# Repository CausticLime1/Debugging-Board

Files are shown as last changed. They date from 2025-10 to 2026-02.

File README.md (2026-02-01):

# Sharkbyte Debugger Board

## Purpose of Project

The purpose of this project is to develop a budget-friendly electronics debugging station that includes various PCBs (Printed Circuit Boards) that incorporate different functionalities. 
A self-designed main board will be used to handle the data processing to display the outputs of the various peripheral boards. The peripheral boards will each have their own functionality and use such 
as an oscilloscope, multimeter, function generator, logic analyzer, variable DC power supply, and CAN Bus debugger. Each board will have a data connector utilizing various GPIO and communication protocols such as
**UART, SPI, and PSSI** as well as a power connector that is handled by the power management system on the main board. 

## Main Board

The central board that all peripheral boards connects to and handles data processing pipeline to a computer. This board has a power management system uses a central 5V rail to provide to a 3.3V LDO for microcontroller logic, and +-12V for operational amplifiers. 

# Notes for Board Redesign

- Make sure boot capacitor for 5V is before the inductor
- Add GPIO reset pin to USB3300

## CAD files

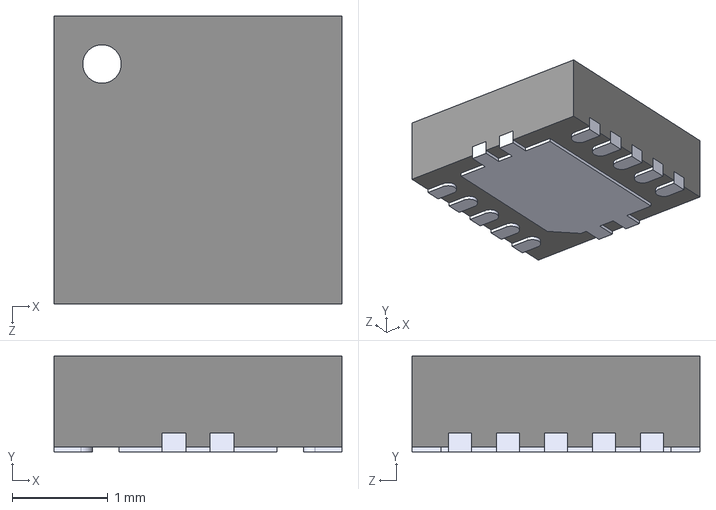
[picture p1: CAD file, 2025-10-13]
Project_Library/ADS8866IDRCR/ADS8866IDRCR.step
3.00 x 1.00 x 3.00 mm

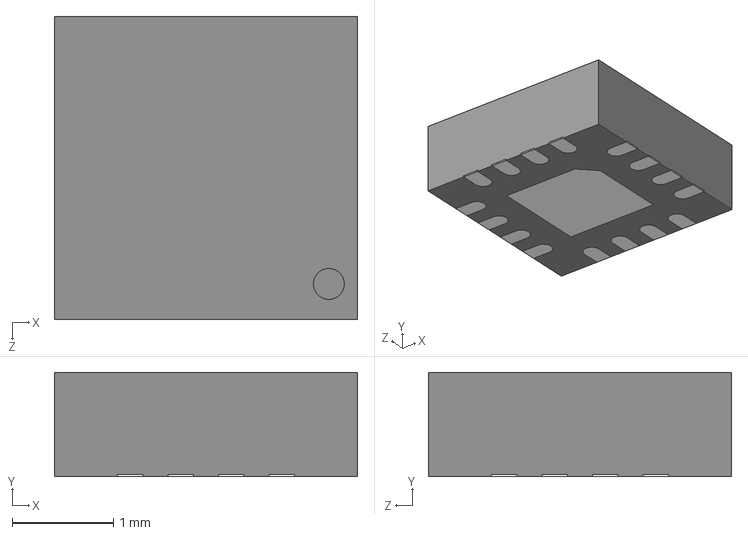
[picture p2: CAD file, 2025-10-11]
Project_Library/LT8609SIV_PBF/LT8609SIV_PBF.step
3.00 x 1.03 x 3.00 mm

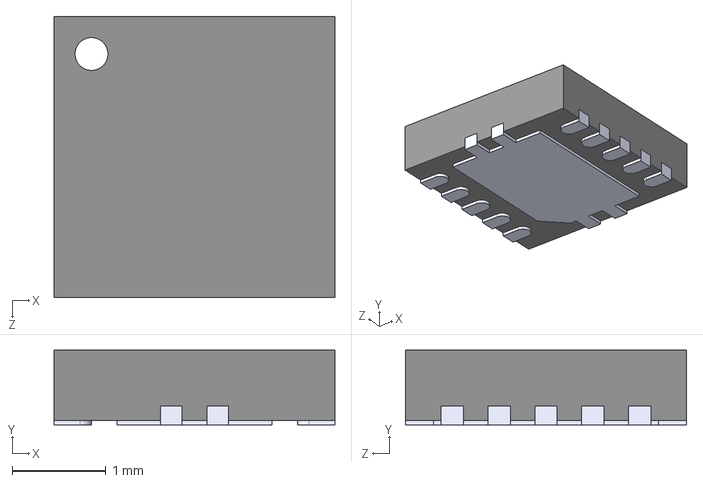
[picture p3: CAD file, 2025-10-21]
Project_Library/PTPS7A9401DSCR/PTPS7A9401DSCR.step
3.00 x 0.8 x 3.00 mm

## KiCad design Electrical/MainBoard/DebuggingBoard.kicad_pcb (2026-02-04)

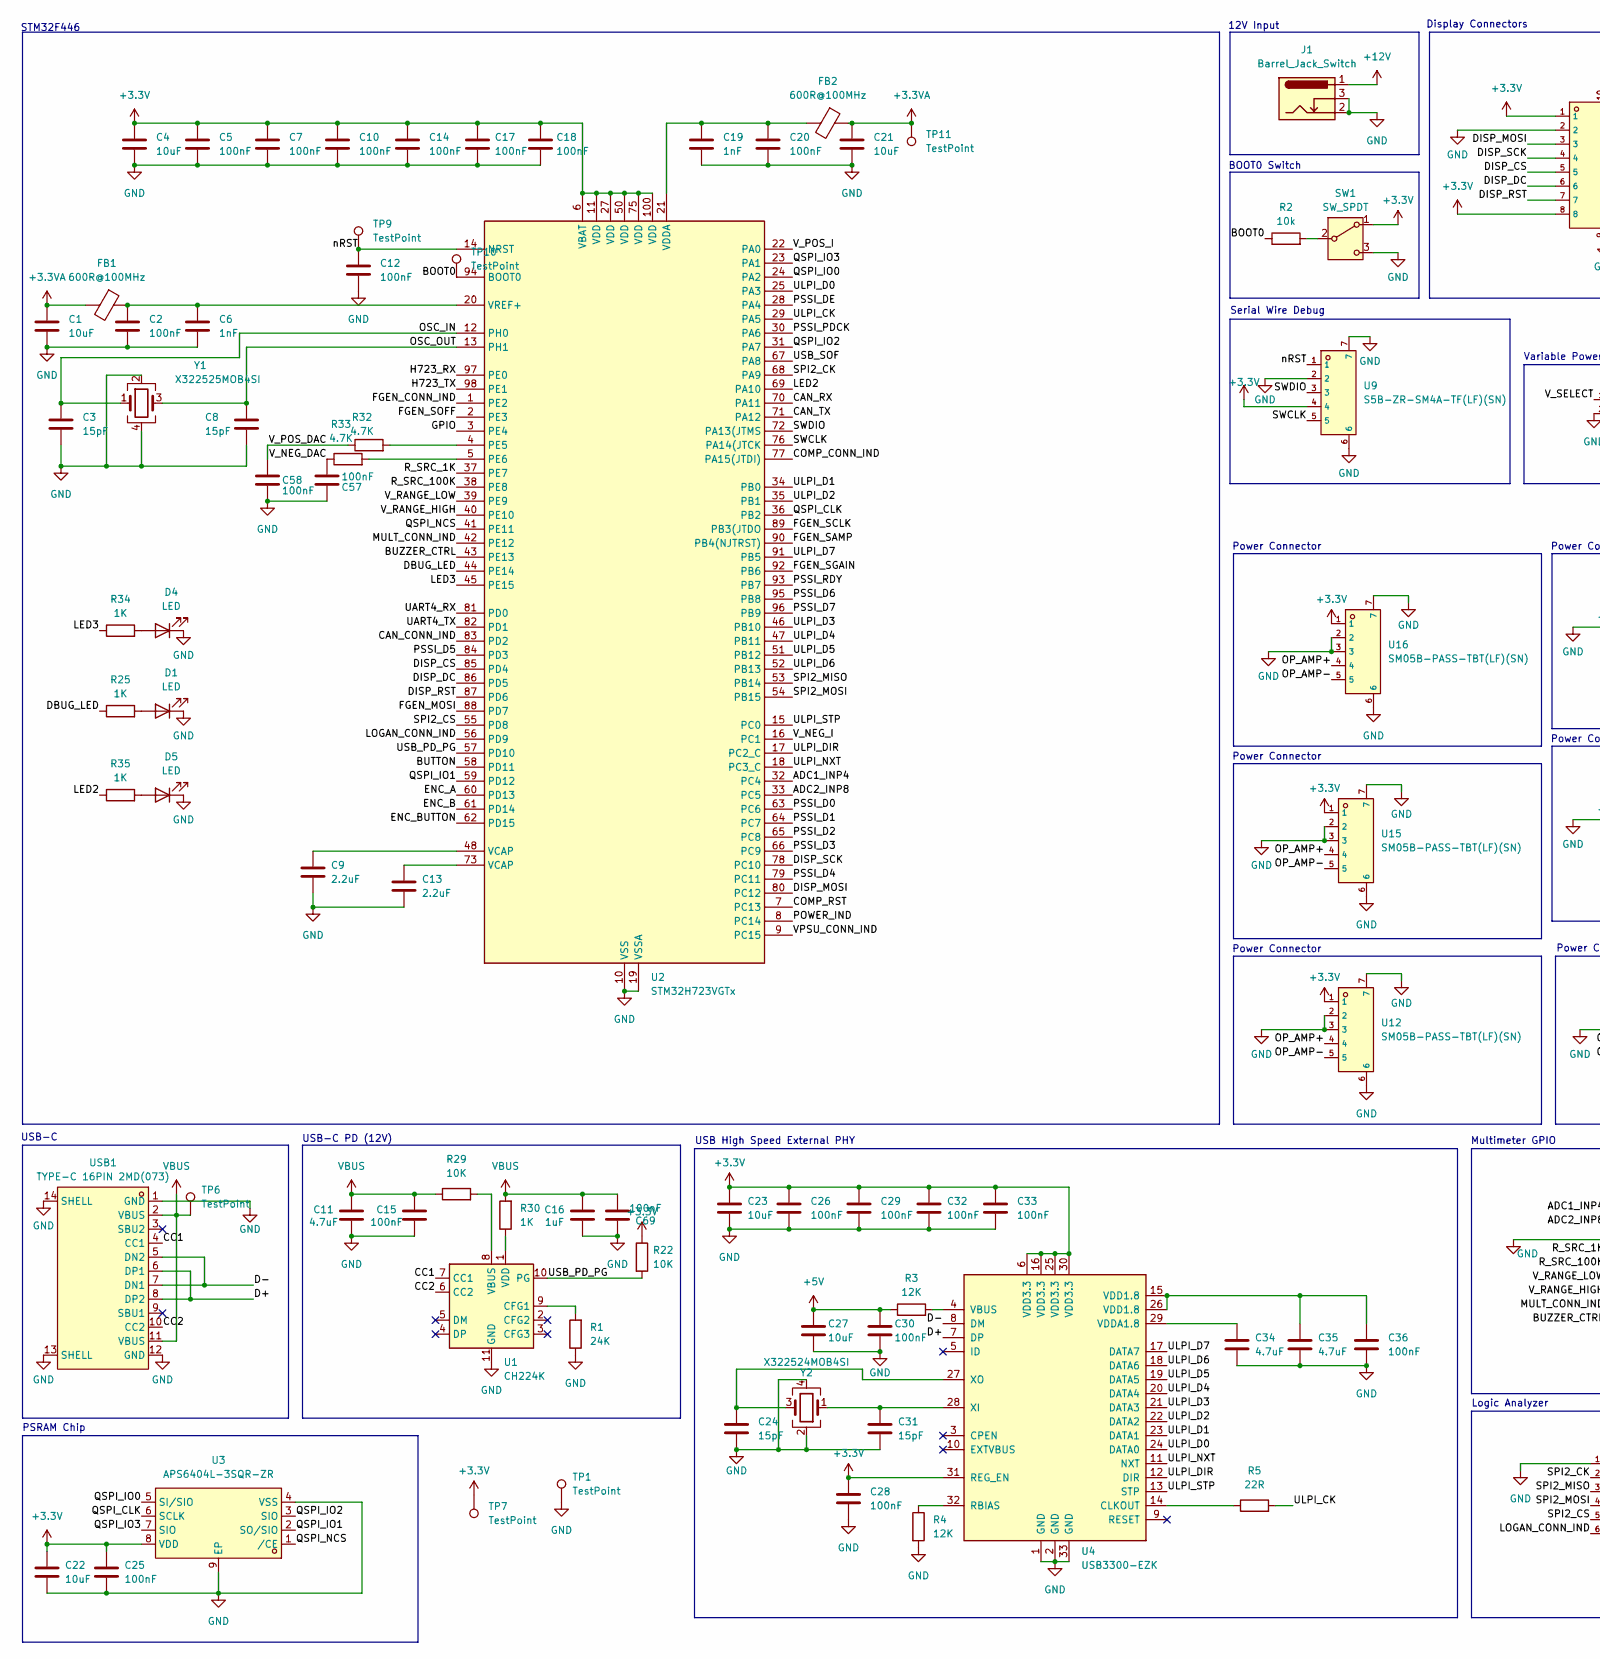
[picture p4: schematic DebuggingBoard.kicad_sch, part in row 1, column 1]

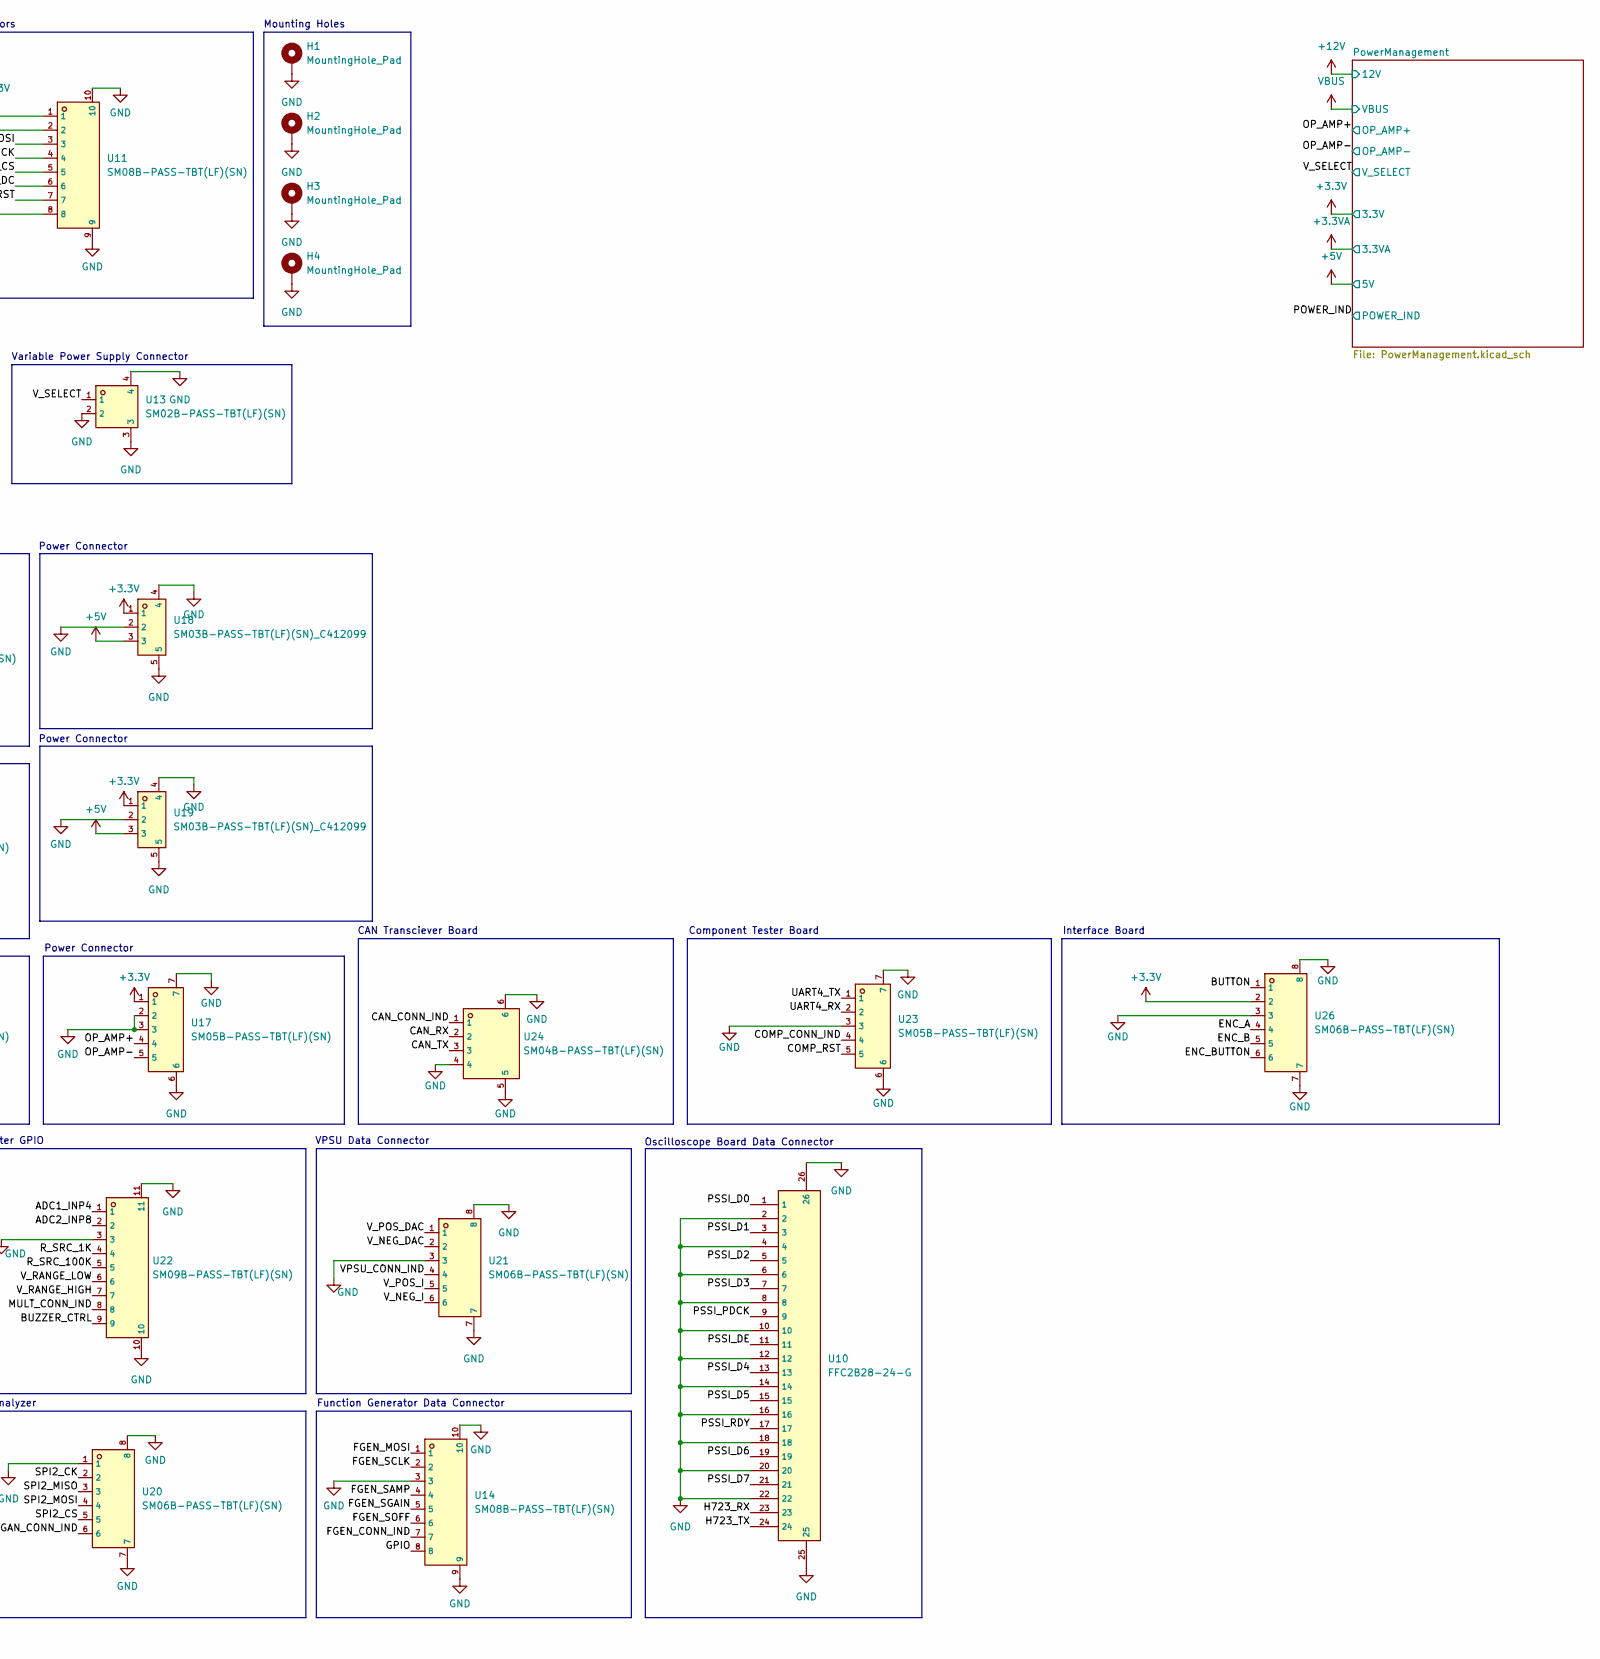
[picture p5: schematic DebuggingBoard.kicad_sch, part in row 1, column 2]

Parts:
C1, C4, C21, C22, C23, C27: 10uF; C_0603_1608Metric
C2, C5, C7, C10, C12, C14, C15, C17, C18, C20, C25, C26, C28, C29, C30, C32, C33, C36, C57, C58, C69: 100nF; C_0402_1005Metric
C3, C8, C24, C31: 15pF; C_0402_1005Metric
C6, C19: 1nF; C_0402_1005Metric
C9, C13: 2.2uF; C_0603_1608Metric
C11: 4.7uF; C_0603_1608Metric
C16: 1uF; C_0603_1608Metric
C34, C35: 4.7uF; C_0402_1005Metric
D1, D4, D5: LED; LED_0603_1608Metric
FB1, FB2: 600R@100MHz; L_0805_2012Metric
H1, H2, H3, H4: MountingHole_Pad; MountingHole_3.2mm_M3_Pad_Via
J1: Barrel_Jack_Switch; BarrelJack_Kycon_KLDX-0202-xC_Horizontal
R1: 24K; R_0603_1608Metric
R2: 10k; R_0402_1005Metric
R3, R4: 12K; R_0402_1005Metric
R5: 22R; R_0402_1005Metric
R22, R29: 10K; R_0402_1005Metric
R25, R34, R35: 1K; R_0402_1005Metric
R30: 1K; R_0603_1608Metric
R32, R33: 4.7K; R_0402_1005Metric
SW1: SW_SPDT; SW_SPDT_CK_JS102011SAQN
TP1, TP6, TP7, TP9, TP10, TP11: TestPoint; TestPoint_Pad_D2.0mm
U1: CH224K; SSOP-10-1EP_3.9x4.9mm_P1mm_EP2.1x3.3mm
U2: STM32H723VGTx; LQFP-100_14x14mm_P0.5mm
U3: APS6404L-3SQR-ZR; USON-8_L3.0-W2.0-P0.50-BL-EP; LCSC Part C3040877
U4: USB3300-EZK; QFN-32-1EP_5x5mm_P0.5mm_EP3.45x3.45mm
U9: S5B-ZR-SM4A-TF(LF)(SN); CONN-SMD_5P-P1.50_S5B-ZR-SM4A-TF-LF-SN; LCSC C485355
U10: FFC2B28-24-G; FPC-SMD_24P-P0.50_XKB_X05A10L24G; LCSC C3151659
U11, U14: SM08B-PASS-TBT(LF)(SN); CONN-SMD_SM08B-PASS-TBT-LF-SN; LCSC C496230
U12, U15, U16, U17, U23: SM05B-PASS-TBT(LF)(SN); CONN-SMD_5P-P2.00_SM05B-PASS-TBT-LF-SN; LCSC C485350
U13: SM02B-PASS-TBT(LF)(SN); CONN-SMD_SM02B-PASS-TBT; LCSC C265417
U18, U19: SM03B-PASS-TBT(LF)(SN)_C412099; CONN-SMD_SM03B-PASS-TBT; LCSC C412099
U20, U21, U26: SM06B-PASS-TBT(LF)(SN); CONN-SMD_SM06B-PASS-TBT; LCSC C489711
U22: SM09B-PASS-TBT(LF)(SN); CONN-SMD_SM09B-PASS-TBT; LCSC C489712
U24: SM04B-PASS-TBT(LF)(SN); CONN-SMD_SM04B-PASS-TBT-LF-SN; LCSC C265073
USB1: TYPE-C 16PIN 2MD(073); USB-C-SMD_TYPE-C-6PIN-2MD-073; LCSC Part C2765186
Y1: X322525MOB4SI; Crystal_SMD_3225-4Pin_3.2x2.5mm
Y2: X322524MOB4SI; Crystal_SMD_3225-4Pin_3.2x2.5mm

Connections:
+3.3V: C4.1, C5.1, C7.1, C10.1, C14.1, C17.1, C18.1, C22.1, C23.1, C25.1, C26.1, C28.1, C29.1, C32.1, C33.1, R22.1, SW1.1 (A), TP7.1, U2.6 (VBAT), U2.11 (VDD), U2.27 (VDD), U2.50 (VDD), U2.75 (VDD), U2.100 (VDD), U3.8 (VDD), U4.6 (VDD3.3), U4.16 (VDD3.3), U4.25 (VDD3.3), U4.30 (VDD3.3), U4.31 (REG_EN), U9.4, U11.1, U11.8, U12.1, U15.1, U16.1, U17.1, U18.1, U19.1, U26.2; also elsewhere on the board
+3.3VA: C1.1, C21.1, FB1.2, FB2.1, TP11.1; also elsewhere on the board
+5V: C27.1, C30.1, R3.1, U18.3, U19.3; also elsewhere on the board
+12V: J1.1; also elsewhere on the board
/ADC1_INP4: U2.32 (PC4), U22.1
/ADC2_INP8: U2.33 (PC5), U22.2
/BOOT0: R2.1, TP10.1, U2.94 (BOOT0)
/BUTTON: U2.58 (PD11), U26.1
/BUZZER_CTRL: U2.43 (PE13), U22.9
/CAN_CONN_IND: U2.83 (PD2), U24.1
/CAN_RX: U2.70 (PA11), U24.2
/CAN_TX: U2.71 (PA12), U24.3
/CC1: U1.7 (CC1), USB1.4 (CC1)
/CC2: U1.6 (CC2), USB1.10 (CC2)
/COMP_CONN_IND: U2.77 (PA15(JTDI)), U23.4
/COMP_RST: U2.7 (PC13), U23.5
/D+: U4.7 (DP), USB1.6 (DP1), USB1.8 (DP2)
/D-: U4.8 (DM), USB1.5 (DN2), USB1.7 (DN1)
/DBUG_LED: R25.1, U2.44 (PE14)
/DISP_CS: U2.85 (PD4), U11.5
/DISP_DC: U2.86 (PD5), U11.6
/DISP_MOSI: U2.80 (PC12), U11.3
/DISP_RST: U2.87 (PD6), U11.7
/DISP_SCK: U2.78 (PC10), U11.4
/ENC_A: U2.60 (PD13), U26.4
/ENC_B: U2.61 (PD14), U26.5
/ENC_BUTTON: U2.62 (PD15), U26.6
/FGEN_CONN_IND: U2.1 (PE2), U14.7
/FGEN_MOSI: U2.88 (PD7), U14.1
/FGEN_SAMP: U2.90 (PB4(NJTRST)), U14.4
/FGEN_SCLK: U2.89 (PB3(JTDO), U14.2
/FGEN_SGAIN: U2.92 (PB6), U14.5
/FGEN_SOFF: U2.2 (PE3), U14.6
/GPIO: U2.3 (PE4), U14.8
/H723_RX: U2.97 (PE0), U10.23
/H723_TX: U2.98 (PE1), U10.24
/LED2: R35.1, U2.69 (PA10)
/LED3: R34.1, U2.45 (PE15)
/LOGAN_CONN_IND: U2.56 (PD9), U20.6
/MULT_CONN_IND: U2.42 (PE12), U22.8
/OP_AMP+: U12.4, U15.4, U16.4, U17.4; also elsewhere on the board
/OP_AMP-: U12.5, U15.5, U16.5, U17.5; also elsewhere on the board
/OSC_IN: C3.1, U2.12 (PH0), Y1.1
/OSC_OUT: C8.1, U2.13 (PH1), Y1.3
/POWER_IND: U2.8 (PC14); also elsewhere on the board
/PSSI_D0: U2.63 (PC6), U10.1
/PSSI_D1: U2.64 (PC7), U10.3
/PSSI_D2: U2.65 (PC8), U10.5
/PSSI_D3: U2.66 (PC9), U10.7
/PSSI_D4: U2.79 (PC11), U10.13
/PSSI_D5: U2.84 (PD3), U10.15
/PSSI_D6: U2.95 (PB8), U10.19
/PSSI_D7: U2.96 (PB9), U10.21
/PSSI_DE: U2.28 (PA4), U10.11
/PSSI_PDCK: U2.30 (PA6), U10.9
/PSSI_RDY: U2.93 (PB7), U10.17
/QSPI_CLK: U2.36 (PB2), U3.6 (SCLK)
/QSPI_IO0: U2.24 (PA2), U3.5 (SI/SIO)
/QSPI_IO1: U2.59 (PD12), U3.2 (SO/SIO)
/QSPI_IO2: U2.31 (PA7), U3.3 (SIO)
/QSPI_IO3: U2.23 (PA1), U3.7 (SIO)
/QSPI_NCS: U2.41 (PE11), U3.1 (/CE)
/R_SRC_1K: U2.37 (PE7), U22.4
/R_SRC_100K: U2.38 (PE8), U22.5
/SPI2_CK: U2.68 (PA9), U20.2
/SPI2_CS: U2.55 (PD8), U20.5
/SPI2_MISO: U2.53 (PB14), U20.3
/SPI2_MOSI: U2.54 (PB15), U20.4
/SWCLK: U2.76 (PA14(JTCK), U9.5
/SWDIO: U2.72 (PA13(JTMS), U9.3
/UART4_RX: U2.81 (PD0), U23.2
/UART4_TX: U2.82 (PD1), U23.1
/ULPI_CK: R5.2, U2.29 (PA5)
/ULPI_D0: U2.25 (PA3), U4.24 (DATA0)
/ULPI_D1: U2.34 (PB0), U4.23 (DATA1)
/ULPI_D2: U2.35 (PB1), U4.22 (DATA2)
/ULPI_D3: U2.46 (PB10), U4.21 (DATA3)
/ULPI_D4: U2.47 (PB11), U4.20 (DATA4)
/ULPI_D5: U2.51 (PB12), U4.19 (DATA5)
/ULPI_D6: U2.52 (PB13), U4.18 (DATA6)
/ULPI_D7: U2.91 (PB5), U4.17 (DATA7)
/ULPI_DIR: U2.17 (PC2_C), U4.12 (DIR)
/ULPI_NXT: U2.18 (PC3_C), U4.11 (NXT)
/ULPI_STP: U2.15 (PC0), U4.13 (STP)
/USB_PD_PG: R22.2, U1.10 (PG), U2.57 (PD10)
/USB_SOF: U2.67 (PA8)
/VPSU_CONN_IND: U2.9 (PC15), U21.4
/V_NEG_DAC: C57.1, R33.1, U21.2
/V_NEG_I: U2.16 (PC1), U21.6
/V_POS_DAC: C58.1, R32.1, U21.1
/V_POS_I: U2.22 (PA0), U21.5
/V_RANGE_HIGH: U2.40 (PE10), U22.7
/V_RANGE_LOW: U2.39 (PE9), U22.6
/V_SELECT: U13.1; also elsewhere on the board
/nRST: C12.1, TP9.1, U2.14 (NRST), U9.1
GND: C1.2, C2.2, C3.2, C4.2, C5.2, C6.2, C7.2, C8.2, C9.2, C10.2, C11.1, C12.2, C13.2, C14.2, C15.1, C16.1, C17.2, C18.2, C19.2, C20.2, C21.2, C22.2, C23.2, C24.2, C25.2, C26.2, C27.2, C28.2, C29.2, C30.2, C31.2, C32.2, C33.2, C34.2, C35.2, C36.2, C57.2, C58.2, C69.2, D1.1 (K), D4.1 (K), D5.1 (K), H1.1, H2.1, H3.1, H4.1, J1.2, J1.3, R1.1, R4.2, SW1.3 (C), TP1.1, U1.11 (GND), U2.10 (VSS), U2.19 (VSSA), U2.26 (VSS), U2.49 (VSS), U2.74 (VSS), U2.99 (VSS), U3.4 (VSS), U3.9 (EP), U4.1 (GND), U4.2 (GND), U4.33 (GND), U9.2, U9.6, U9.7, U10.2, U10.4, U10.6, U10.8, U10.10, U10.12, U10.14, U10.16, U10.18, U10.20, U10.22, U10.25, U10.26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; also elsewhere on the board
unnamed: C9.1, U2.48 (VCAP)
unnamed: C13.1, U2.73 (VCAP)
unnamed: C35.1, C36.1, U4.15 (VDD1.8), U4.26 (VDD1.8)
unnamed: D1.2 (A), R25.2
unnamed: D4.2 (A), R34.2
unnamed: D5.2 (A), R35.2
unnamed: R2.2, SW1.2 (B)
unnamed: R1.2, U1.9 (CFG1)
unnamed: R29.2, U1.8 (VBUS)
unnamed: R30.1, U1.1 (VDD)
unnamed: R32.2, U2.4 (PE5)
unnamed: R33.2, U2.5 (PE6)
unnamed: C19.1, C20.1, FB2.2, U2.21 (VDDA)
unnamed: C2.1, C6.1, FB1.1, U2.20 (VREF+)
unnamed: R5.1, U4.14 (CLKOUT)
unnamed: R4.1, U4.32 (RBIAS)
unnamed: R3.2, U4.4 (VBUS)
unnamed: C34.1, U4.29 (VDDA1.8)
unnamed: C31.1, U4.28 (XI), Y2.1
unnamed: C24.1, U4.27 (XO), Y2.3
VBUS: C11.2, C15.2, C16.2, C69.1, R29.1, R30.2, TP6.1, USB1.2 (VBUS), USB1.11 (VBUS); also elsewhere on the board

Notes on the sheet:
USB-C
Oscilloscope Board Data Connector
Mounting Holes
PSRAM Chip
Power Connector
Interface Board
Component Tester Board
BOOT0 Switch
CAN Transciever Board
USB High Speed External PHY
USB-C PD (12V)
Variable Power Supply Connector
Function Generator Data Connector
Display Connectors
Logic Analyzer
Multimeter GPIO
12V Input
STM32F446
Serial Wire Debug
VPSU Data Connector

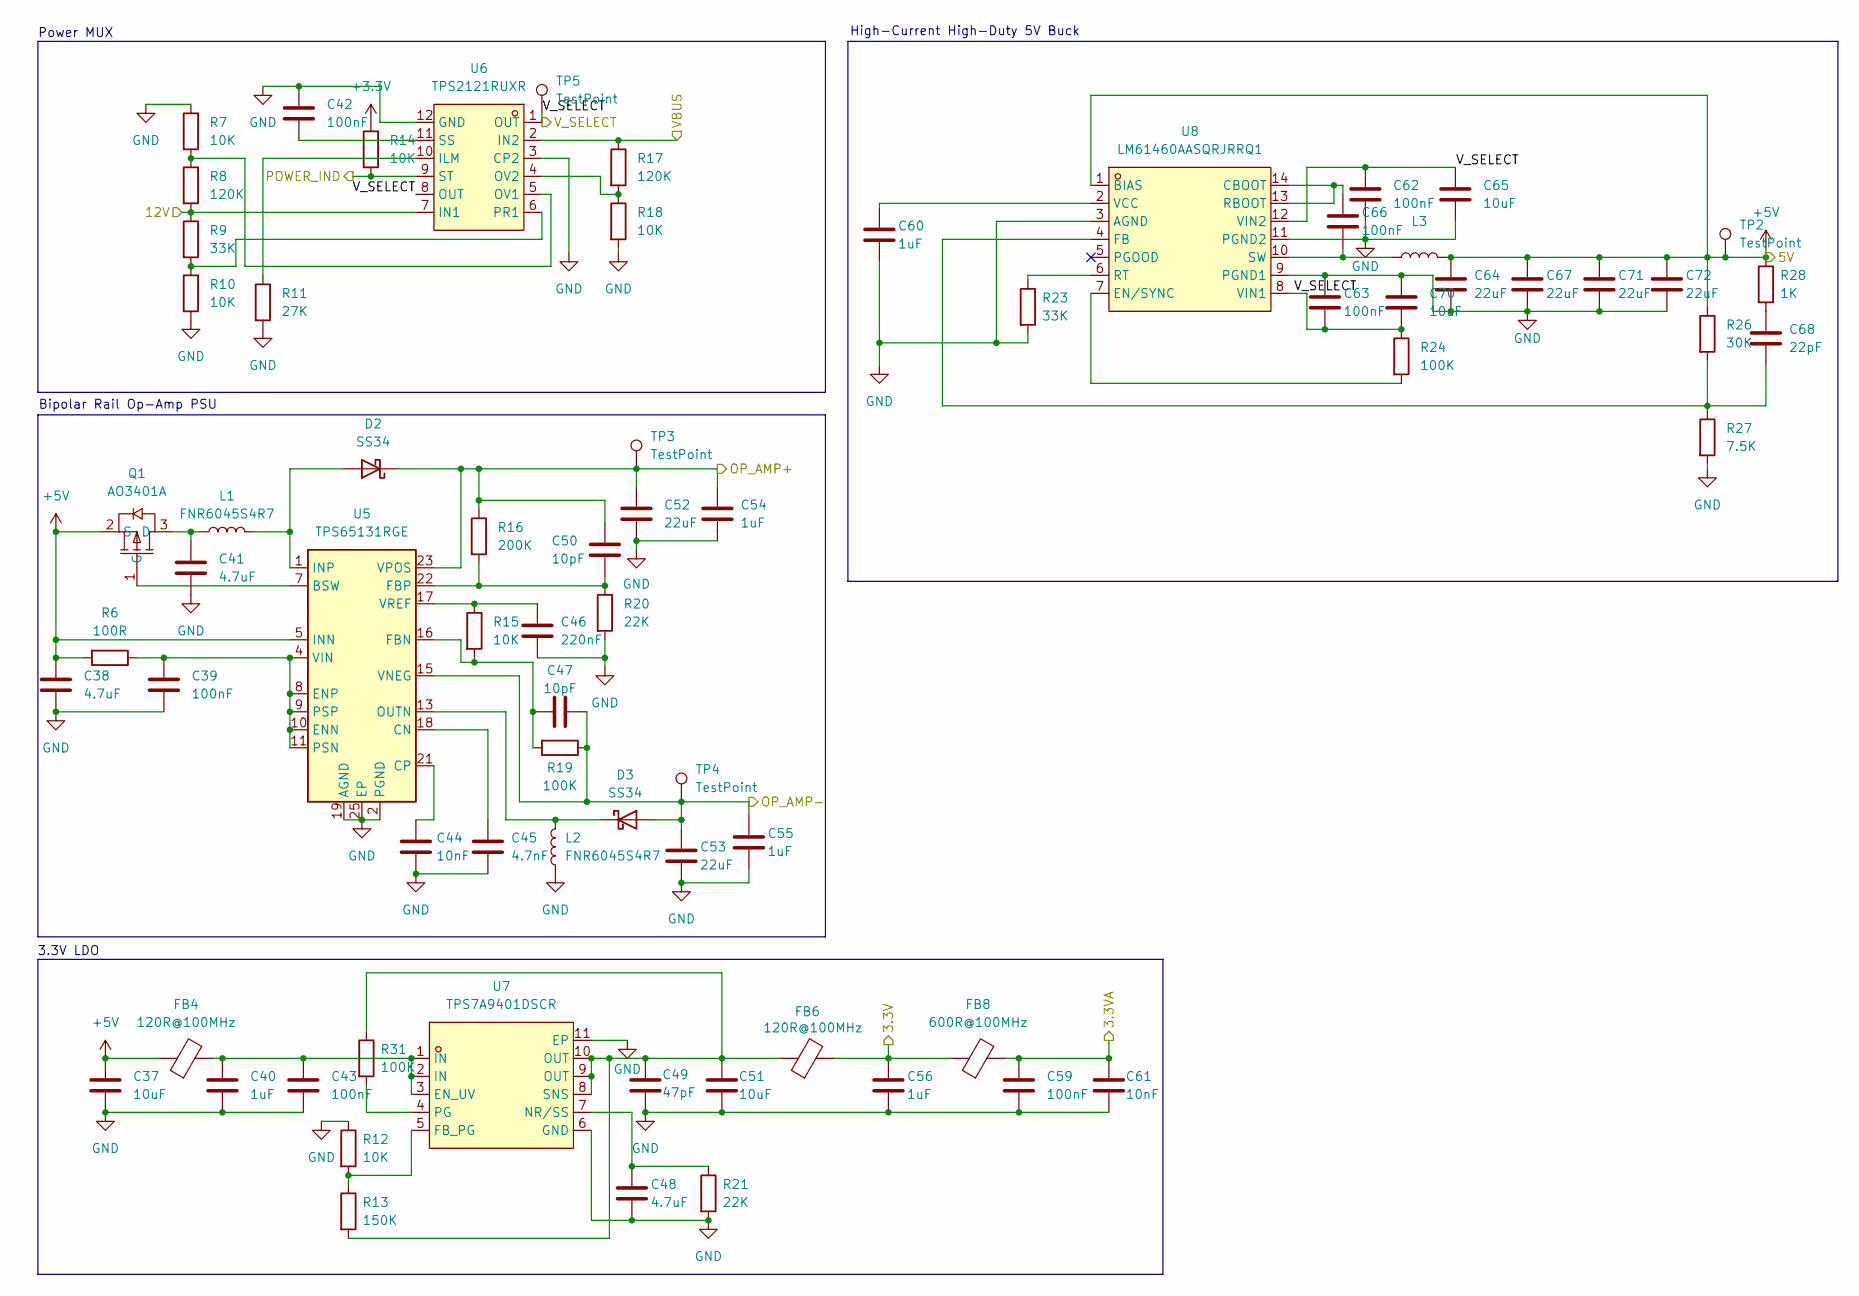
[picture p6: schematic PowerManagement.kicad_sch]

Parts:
C37, C51, C65, C70: 10uF; C_0603_1608Metric
C38, C41, C48: 4.7uF; C_0603_1608Metric
C39, C42, C43, C59, C62, C63, C66: 100nF; C_0402_1005Metric
C40, C54, C55, C56, C60: 1uF; C_0603_1608Metric
C44, C61: 10nF; C_0402_1005Metric
C45: 4.7nF; C_0402_1005Metric
C46: 220nF; C_0402_1005Metric
C47, C50: 10pF; C_0402_1005Metric
C49: 47pF; C_0402_1005Metric
C52, C53, C64, C67, C71, C72: 22uF; C_0805_2012Metric
C68: 22pF; C_0402_1005Metric
D2, D3: SS34; D_SMA
FB4, FB6: 120R@100MHz; L_0603_1608Metric
FB8: 600R@100MHz; L_0805_2012Metric
L1, L2, L3: FNR6045S4R7; L_Changjiang_FNR6045S
Q1: AO3401A; SOT-23_L2.9-W1.3-P1.90-LS2.4-BR; LCSC Part C15127
R6: 100R; R_0402_1005Metric
R7, R10, R18: 10K; R_0603_1608Metric
R8, R17: 120K; R_0603_1608Metric
R9: 33K; R_0603_1608Metric
R11: 27K; R_0603_1608Metric
R12, R14, R15: 10K; R_0402_1005Metric
R13: 150K; R_0603_1608Metric
R16: 200K; R_0402_1005Metric
R19, R24, R31: 100K; R_0402_1005Metric
R20, R21: 22K; R_0402_1005Metric
R23: 33K; R_0402_1005Metric
R26: 30K; R_0603_1608Metric
R27: 7.5K; R_0603_1608Metric
R28: 1K; R_0402_1005Metric
TP2, TP3, TP4, TP5: TestPoint; TestPoint_Pad_D2.0mm
U5: TPS65131RGE; VQFN-24-1EP_4x4mm_P0.5mm_EP2.45x2.45mm_ThermalVias
U6: TPS2121RUXR; VQFN-HR-12_L2.5-W2.0-P0.50-BL; LCSC Part C485916
U7: TPS7A9401DSCR; WSON-10_L3.0-W3.0-P0.50-TL-EP; LCSC Part C5220127
U8: LM61460AASQRJRRQ1; VQFN-14-HR_L4.0-W3.5-TL_LM61460AASQRJRRQ1; LCSC Part C1855832

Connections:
+3.3V: C56.1, FB6.2, FB8.1, R14.1; also elsewhere on the board
+3.3VA: C59.1, C61.1, FB8.2; also elsewhere on the board
+5V: C37.1, C38.1, C64.1, C67.1, C71.1, C72.1, FB4.1, L3.2, Q1.2 (S), R6.2, R26.1, R28.1, TP2.1, U5.5 (INN), U5.6 (INN), U8.1 (BIAS); also elsewhere on the board
+12V: R8.2, R9.1, U6.7 (IN1); also elsewhere on the board
/OP_AMP+: C50.1, C52.1, C54.1, D2.1 (K), R16.1, TP3.1, U5.23 (VPOS); also elsewhere on the board
/OP_AMP-: C47.2, C53.1, C55.1, D3.2 (A), R19.1, TP4.1, U5.15 (VNEG); also elsewhere on the board
/POWER_IND: R14.2, U6.9 (ST); also elsewhere on the board
/V_SELECT: C62.1, C63.2, C65.1, C70.2, R24.1, TP5.1, U6.1 (OUT), U6.8 (OUT), U8.8 (VIN1), U8.12 (VIN2); also elsewhere on the board
GND: C37.2, C38.2, C39.2, C40.2, C41.2, C42.1, C43.2, C44.2, C45.2, C46.2, C48.2, C49.2, C51.2, C52.2, C53.2, C54.2, C55.2, C56.2, C59.2, C60.2, C61.2, C62.2, C63.1, C64.2, C65.2, C67.2, C70.1, C71.2, C72.2, L2.1, R7.1, R10.2, R11.2, R12.1, R18.2, R20.2, R21.2, R23.2, R27.2, U5.2 (PGND), U5.3 (PGND), U5.19 (AGND), U5.25 (EP), U6.3 (CP2), U6.12 (GND), U7.6 (GND), U7.11 (EP), U8.3 (AGND), U8.9 (PGND1), U8.11 (PGND2); also elsewhere on the board
unnamed: C68.1, R28.2
unnamed: D2.2 (A), L1.2, U5.1 (INP), U5.24 (INP)
unnamed: D3.1 (K), L2.2, U5.13 (OUTN), U5.14 (OUTN)
unnamed: C41.1, L1.1, Q1.3 (D)
unnamed: Q1.1 (G), U5.7 (BSW)
unnamed: C45.1, U5.18 (CN)
unnamed: C44.1, U5.21 (CP)
unnamed: C39.1, R6.1, U5.4 (VIN), U5.8 (ENP), U5.9 (PSP), U5.10 (ENN), U5.11 (PSN)
unnamed: C47.1, R15.2, R19.2, U5.16 (FBN)
unnamed: C50.2, R16.2, R20.1, U5.22 (FBP)
unnamed: C46.1, R15.1, U5.17 (VREF)
unnamed: R11.1, U6.10 (ILM)
unnamed: R7.2, R8.1, U6.5 (OV1)
unnamed: R17.2, R18.1, U6.4 (OV2)
unnamed: R9.2, R10.1, U6.6 (PR1)
unnamed: C42.2, U6.11 (SS)
unnamed: C40.1, C43.1, FB4.2, U7.1 (IN), U7.2 (IN), U7.3 (EN_UV)
unnamed: R12.2, R13.1, U7.5 (FB_PG)
unnamed: C48.1, R21.1, U7.7 (NR/SS)
unnamed: R31.2, U7.4 (PG)
unnamed: C49.1, C51.1, FB6.1, R13.2, R31.1, U7.8 (SNS), U7.9 (OUT), U7.10 (OUT)
unnamed: C66.1, U8.13 (RBOOT), U8.14 (CBOOT)
unnamed: R24.2, U8.7 (EN/SYNC)
unnamed: C68.2, R26.2, R27.1, U8.4 (FB)
unnamed: R23.1, U8.6 (RT)
unnamed: C66.2, L3.1, U8.10 (SW)
unnamed: C60.1, U8.2 (VCC)
VBUS: R17.1, U6.2 (IN2); also elsewhere on the board

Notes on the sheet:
Power MUX
High-Current High-Duty 5V Buck
Bipolar Rail Op-Amp PSU
3.3V LDO

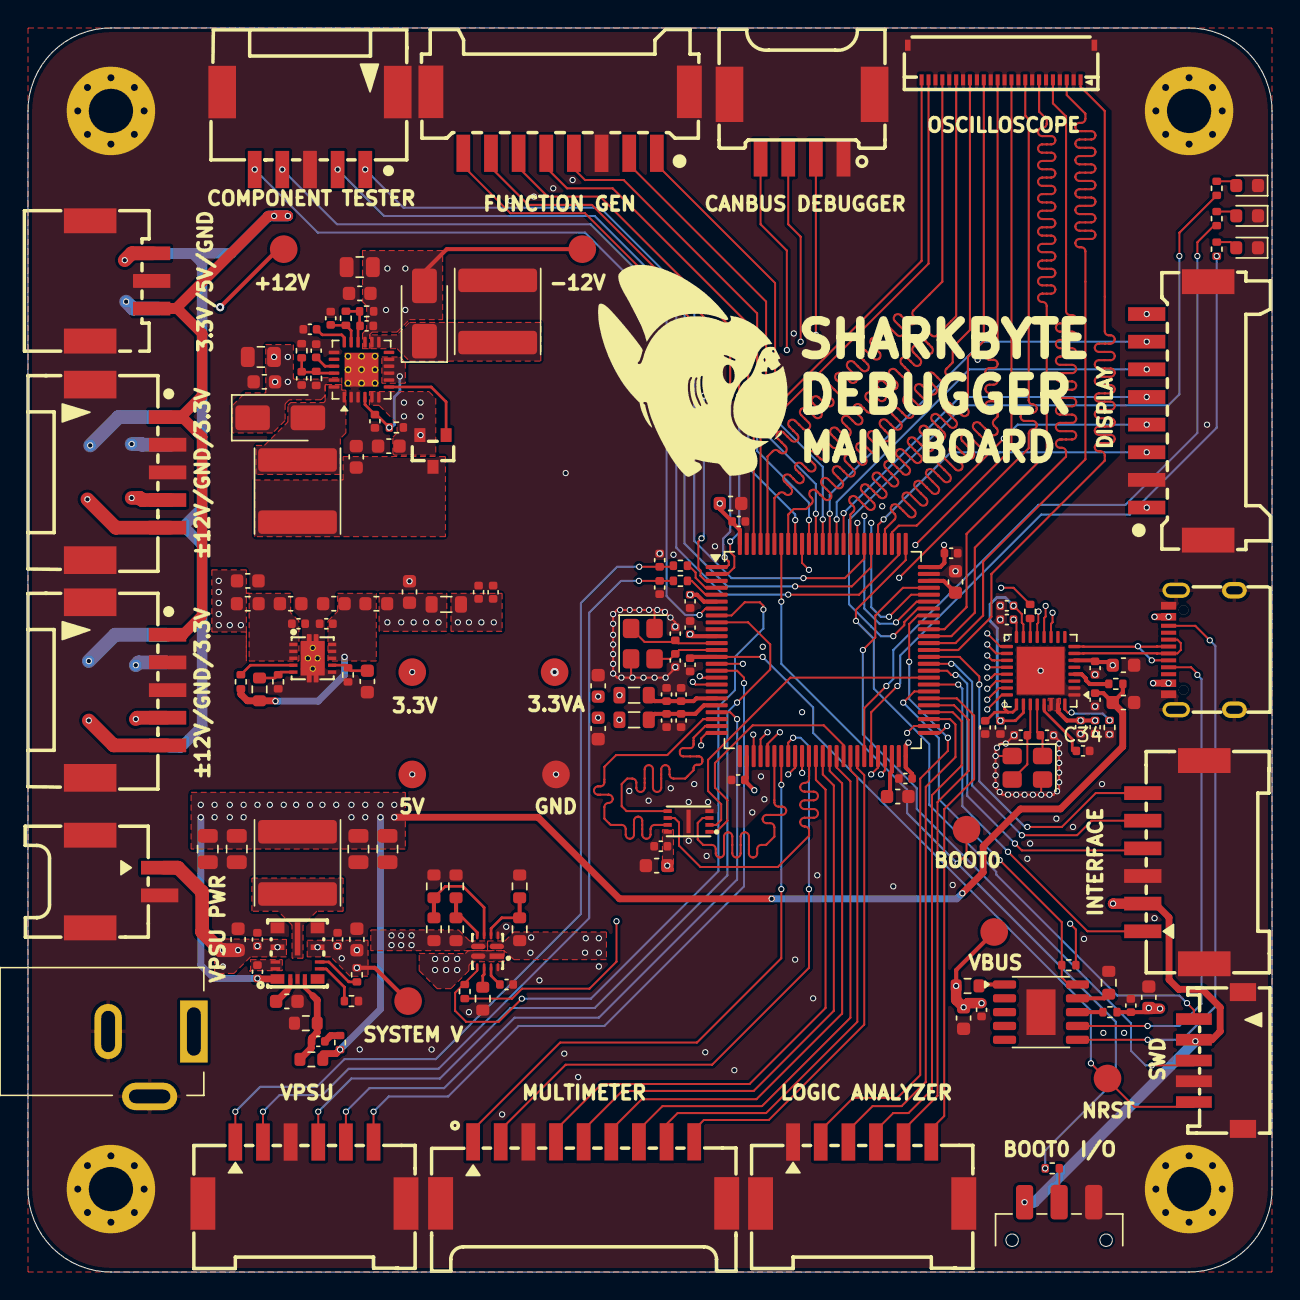
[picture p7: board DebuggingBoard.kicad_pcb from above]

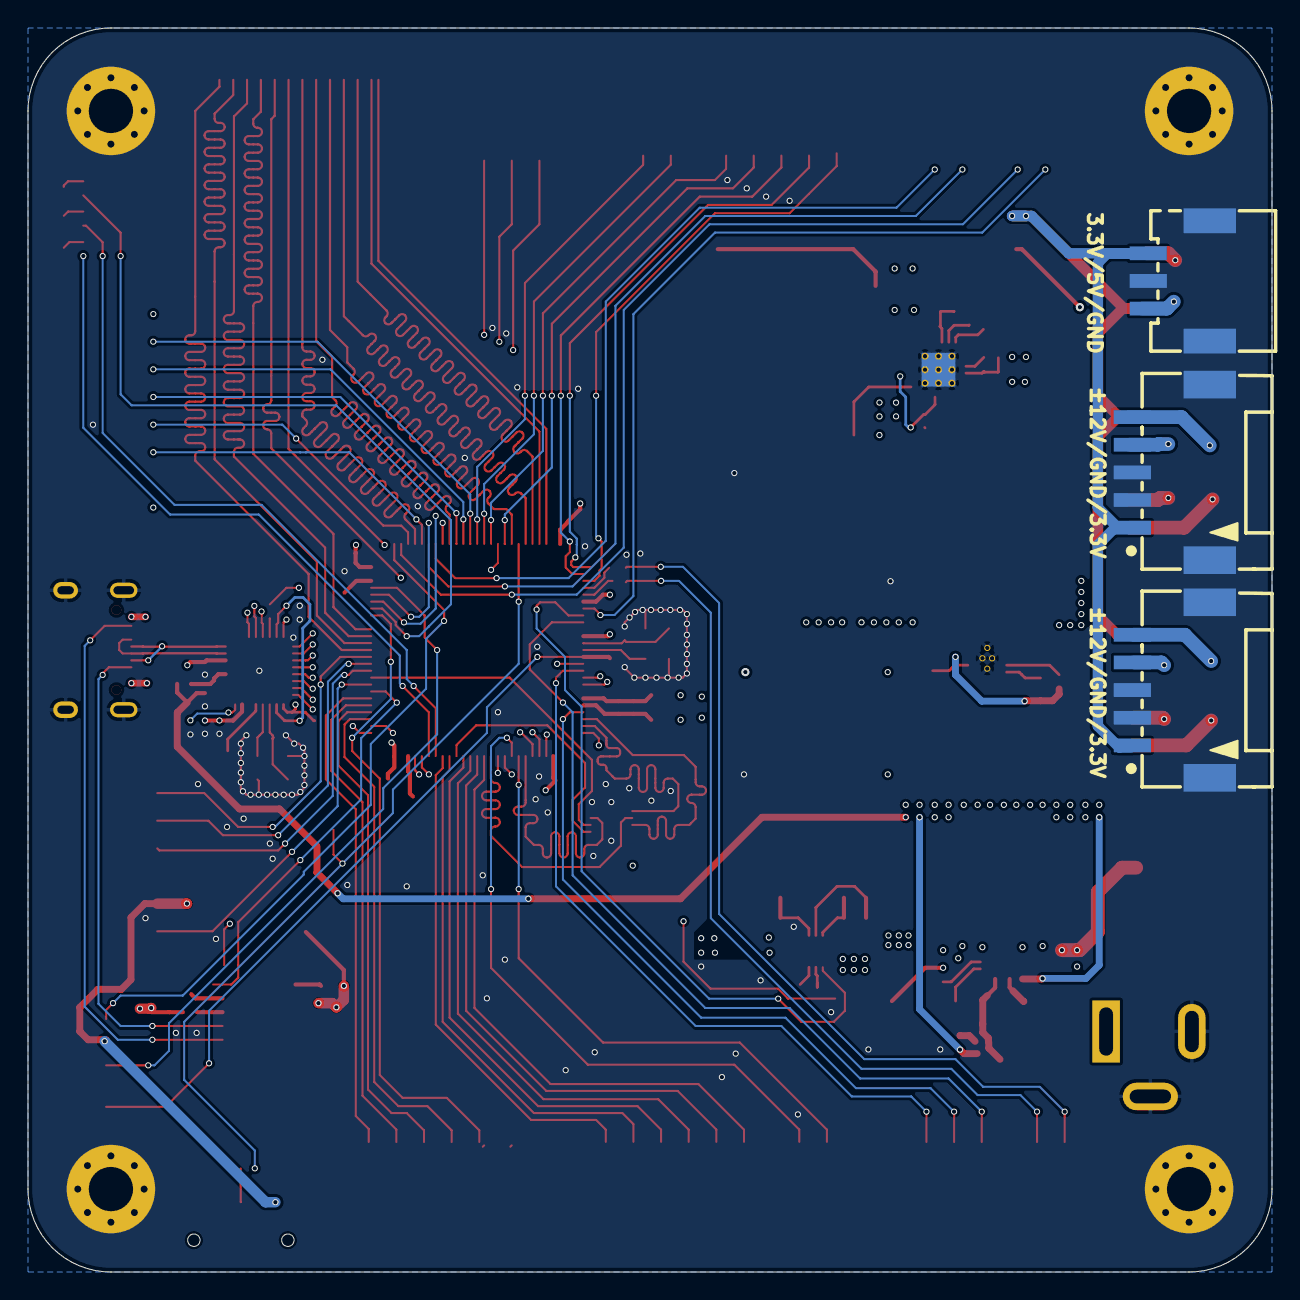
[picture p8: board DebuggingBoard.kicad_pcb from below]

Board: 6 copper layers, 90.0 x 90.0 mm, 165 parts (3 on the bottom side), 143 nets.

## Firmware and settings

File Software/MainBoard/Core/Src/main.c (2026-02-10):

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
/* Includes ------------------------------------------------------------------*/
#include "main.h"
#include <string.h>      // Required for strlen()
#include <stdio.h>       // Required for sprintf()
#include "cmsis_os.h"
#include "usb_device.h"

ADC_HandleTypeDef hadc1;
ADC_HandleTypeDef hadc2;
DMA_HandleTypeDef hdma_adc1;

FDCAN_HandleTypeDef hfdcan1;

OSPI_HandleTypeDef hospi1;

PSSI_HandleTypeDef hpssi;

SPI_HandleTypeDef hspi1;
SPI_HandleTypeDef hspi2;
SPI_HandleTypeDef hspi3;
DMA_HandleTypeDef hdma_spi1_tx;
DMA_HandleTypeDef hdma_spi2_rx;
DMA_HandleTypeDef hdma_spi2_tx;
DMA_HandleTypeDef hdma_spi3_tx;

TIM_HandleTypeDef htim1;
TIM_HandleTypeDef htim15;

UART_HandleTypeDef huart4;
UART_HandleTypeDef huart8;

/* Definitions for defaultTask */
osThreadId_t defaultTaskHandle;
const osThreadAttr_t defaultTask_attributes = {
  .name = "defaultTask",
  .stack_size = 512 * 4,
  .priority = (osPriority_t) osPriorityNormal,
};
/* Definitions for task_Acquisitio */
osThreadId_t task_AcquisitioHandle;
const osThreadAttr_t task_Acquisitio_attributes = {
  .name = "task_Acquisitio",
  .stack_size = 1024 * 4,
  .priority = (osPriority_t) osPriorityHigh,
};
/* Definitions for task_Comms */
osThreadId_t task_CommsHandle;
const osThreadAttr_t task_Comms_attributes = {
  .name = "task_Comms",
  .stack_size = 2048 * 4,
  .priority = (osPriority_t) osPriorityAboveNormal,
};
/* Definitions for task_Control */
osThreadId_t task_ControlHandle;
const osThreadAttr_t task_Control_attributes = {
  .name = "task_Control",
  .stack_size = 1024 * 4,
  .priority = (osPriority_t) osPriorityNormal,
};
/* Definitions for task_GUI */
osThreadId_t task_GUIHandle;
const osThreadAttr_t task_GUI_attributes = {
  .name = "task_GUI",
  .stack_size = 4096 * 4,
  .priority = (osPriority_t) osPriorityLow,
};
void SystemClock_Config(void);
void PeriphCommonClock_Config(void);
static void MPU_Config(void);
static void MX_GPIO_Init(void);
static void MX_DMA_Init(void);
static void MX_PSSI_Init(void);
static void MX_ADC1_Init(void);
static void MX_ADC2_Init(void);
static void MX_SPI1_Init(void);
static void MX_SPI2_Init(void);
static void MX_SPI3_Init(void);
static void MX_TIM1_Init(void);
static void MX_UART8_Init(void);
static void MX_FDCAN1_Init(void);
static void MX_TIM15_Init(void);
static void MX_UART4_Init(void);
static void MX_OCTOSPI1_Init(void);
void StartDefaultTask(void *argument);
void StartAcquisition(void *argument);
void StartComms(void *argument);
void StartControl(void *argument);
void StartGUI(void *argument);

/**
  * @brief  The application entry point.
  * @retval int
  */
int main(void)
{

  /* MPU Configuration--------------------------------------------------------*/
  MPU_Config();

  /* MCU Configuration--------------------------------------------------------*/

  /* Reset of all peripherals, Initializes the Flash interface and the Systick. */
  HAL_Init();

  /* Configure the system clock */
  SystemClock_Config();

  /* Configure the peripherals common clocks */
  PeriphCommonClock_Config();

  /* Initialize all configured peripherals */
  MX_GPIO_Init();
  MX_DMA_Init();
  MX_PSSI_Init();
  MX_ADC1_Init();
  MX_ADC2_Init();
  MX_SPI1_Init();
  MX_SPI2_Init();
  MX_SPI3_Init();
  MX_TIM1_Init();
  MX_UART8_Init();
  MX_FDCAN1_Init();
  MX_TIM15_Init();
  MX_UART4_Init();
  MX_OCTOSPI1_Init();
  /* USER CODE BEGIN 2 */
  __HAL_RCC_SYSCFG_CLK_ENABLE();
  HAL_SYSCFG_AnalogSwitchConfig(SYSCFG_SWITCH_PC2, SYSCFG_SWITCH_PC2_CLOSE);
  HAL_SYSCFG_AnalogSwitchConfig(SYSCFG_SWITCH_PC3, SYSCFG_SWITCH_PC3_CLOSE);
  /* USER CODE END 2 */

  /* Init scheduler */
  osKernelInitialize();

  /* USER CODE BEGIN RTOS_MUTEX */
  /* add mutexes, ... */
  /* USER CODE END RTOS_MUTEX */

  /* USER CODE BEGIN RTOS_SEMAPHORES */
  /* add semaphores, ... */
  /* USER CODE END RTOS_SEMAPHORES */

  /* USER CODE BEGIN RTOS_TIMERS */
  /* start timers, add new ones, ... */
  /* USER CODE END RTOS_TIMERS */

  /* USER CODE BEGIN RTOS_QUEUES */
  /* add queues, ... */
  /* USER CODE END RTOS_QUEUES */

  /* Create the thread(s) */
  /* creation of defaultTask */
  defaultTaskHandle = osThreadNew(StartDefaultTask, NULL, &defaultTask_attributes);

  /* creation of task_Acquisitio */
  task_AcquisitioHandle = osThreadNew(StartAcquisition, NULL, &task_Acquisitio_attributes);

  /* creation of task_Comms */
  task_CommsHandle = osThreadNew(StartComms, NULL, &task_Comms_attributes);

  /* creation of task_Control */
  task_ControlHandle = osThreadNew(StartControl, NULL, &task_Control_attributes);

  /* creation of task_GUI */
  task_GUIHandle = osThreadNew(StartGUI, NULL, &task_GUI_attributes);

  /* USER CODE BEGIN RTOS_THREADS */
  /* add threads, ... */
  /* USER CODE END RTOS_THREADS */

  /* USER CODE BEGIN RTOS_EVENTS */
  /* add events, ... */
  /* USER CODE END RTOS_EVENTS */

  /* Start scheduler */
  osKernelStart();

  /* We should never get here as control is now taken by the scheduler */

  /* Infinite loop */
  /* USER CODE BEGIN WHILE */
  while (1)
  {
    /* USER CODE END WHILE */

    /* USER CODE BEGIN 3 */
  }
  /* USER CODE END 3 */
}

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
/* USER CODE BEGIN 4 */
/**
 * @brief  Sends a string over USB CDC High Speed.
 * @param  str: Pointer to the string to send.
 * @retval 0 if success, 1 if busy/error.
 */
uint8_t USB_Print(char* str)
{
  uint8_t result =USBD_OK;
  uint16_t len = strlen(str);

  // Send the data using the High-Speed function
  // CDC_Transmit_HS is defined in usbd_cdc_if.c
  result = CDC_Transmit_HS((uint8_t*)str, len);

  return result;
}
/* USER CODE END 4 */

/* USER CODE BEGIN Header_StartDefaultTask */
/**
  * @brief  Function implementing the defaultTask thread.
  * @param  argument: Not used
  * @retval None
  */
/* USER CODE END Header_StartDefaultTask */
void StartDefaultTask(void *argument)
{
  /* init code for USB_DEVICE */
  MX_USB_DEVICE_Init();
  /* USER CODE BEGIN 5 */
  /* Infinite loop */
  for(;;)
  {
	 HAL_GPIO_TogglePin(GPIOA, GPIO_PIN_10); // Heartbeat LED
	 osDelay(500);
  }
  /* USER CODE END 5 */
}

/* USER CODE BEGIN Header_StartAcquisition */
/**
* @brief Function implementing the task_Acquisitio thread.
* @param argument: Not used
* @retval None
*/
/* USER CODE END Header_StartAcquisition */
void StartAcquisition(void *argument)
{
  /* USER CODE BEGIN StartAcquisition */
  /* Infinite loop */
  for(;;)
  {
    osDelay(1);
  }
  /* USER CODE END StartAcquisition */
}

/* USER CODE BEGIN Header_StartComms */
/**
* @brief Function implementing the task_Comms thread.
* @param argument: Not used
* @retval None
*/
/* USER CODE END Header_StartComms */
void StartComms(void *argument)
{
  /* USER CODE BEGIN StartComms */
  /* Infinite loop */
	char buffer[64];
	  int count = 0;

	  /* Infinite loop */
	  for(;;)
	  {
		// 1. Format a string
		sprintf(buffer, "Counter Value: %d\r\n", count++);

		// 2. Send it
		uint8_t status = USB_Print(buffer);

		// 3. Simple error handling
		if (status == USBD_BUSY) {
		   // Optional: Wait or retry
		}

		// 4. Wait 100ms
		osDelay(100);
	  }
  /* USER CODE END StartComms */
}

/* USER CODE BEGIN Header_StartControl */
/**
* @brief Function implementing the task_Control thread.
* @param argument: Not used
* @retval None
*/
/* USER CODE END Header_StartControl */
void StartControl(void *argument)
{
  /* USER CODE BEGIN StartControl */
  /* Infinite loop */
  for(;;)
  {
    osDelay(1);
  }
  /* USER CODE END StartControl */
}

/* USER CODE BEGIN Header_StartGUI */
/**
* @brief Function implementing the task_GUI thread.
* @param argument: Not used
* @retval None
*/
/* USER CODE END Header_StartGUI */
void StartGUI(void *argument)
{
  /* USER CODE BEGIN StartGUI */
  /* Infinite loop */
  for(;;)
  {
    osDelay(1);
  }
  /* USER CODE END StartGUI */
}

 /* MPU Configuration */

void MPU_Config(void)
{
  MPU_Region_InitTypeDef MPU_InitStruct = {0};

  /* Disables the MPU */
  HAL_MPU_Disable();

  /* 1. Configure the Background Region (Allows access to everything by default) */
  /* Without this, the chip faults immediately because NO_ACCESS is the default */
  MPU_InitStruct.Enable = MPU_REGION_ENABLE;
  MPU_InitStruct.Number = MPU_REGION_NUMBER0;
  MPU_InitStruct.BaseAddress = 0x0;
  MPU_InitStruct.Size = MPU_REGION_SIZE_4GB;
  MPU_InitStruct.SubRegionDisable = 0x87;
  MPU_InitStruct.TypeExtField = MPU_TEX_LEVEL0;
  MPU_InitStruct.AccessPermission = MPU_REGION_FULL_ACCESS; // CHANGED from NO_ACCESS
  MPU_InitStruct.DisableExec = MPU_INSTRUCTION_ACCESS_ENABLE;
  MPU_InitStruct.IsShareable = MPU_ACCESS_NOT_SHAREABLE;
  MPU_InitStruct.IsCacheable = MPU_ACCESS_CACHEABLE;
  MPU_InitStruct.IsBufferable = MPU_ACCESS_BUFFERABLE;
  HAL_MPU_ConfigRegion(&MPU_InitStruct);

  /* 2. Configure RAM_D2 (0x30000000) as Non-Cacheable for USB/DMA */
  MPU_InitStruct.Enable = MPU_REGION_ENABLE;
  MPU_InitStruct.Number = MPU_REGION_NUMBER1; // Use Region 1
  MPU_InitStruct.BaseAddress = 0x30000000;
  MPU_InitStruct.Size = MPU_REGION_SIZE_32KB; // Matches your Linker Script
  MPU_InitStruct.SubRegionDisable = 0x0;
  MPU_InitStruct.TypeExtField = MPU_TEX_LEVEL1;
  MPU_InitStruct.AccessPermission = MPU_REGION_FULL_ACCESS;
  MPU_InitStruct.DisableExec = MPU_INSTRUCTION_ACCESS_DISABLE;
  MPU_InitStruct.IsShareable = MPU_ACCESS_SHAREABLE;
  MPU_InitStruct.IsCacheable = MPU_ACCESS_NOT_CACHEABLE; // CRITICAL: No Cache
  MPU_InitStruct.IsBufferable = MPU_ACCESS_NOT_BUFFERABLE;
  HAL_MPU_ConfigRegion(&MPU_InitStruct);

  /* Enables the MPU */
  HAL_MPU_Enable(MPU_PRIVILEGED_DEFAULT);
}

/**
  * @brief  Period elapsed callback in non blocking mode
  * @note   This function is called  when TIM6 interrupt took place, inside
  * HAL_TIM_IRQHandler(). It makes a direct call to HAL_IncTick() to increment
  * a global variable "uwTick" used as application time base.
  * @param  htim : TIM handle
  * @retval None
  */
void HAL_TIM_PeriodElapsedCallback(TIM_HandleTypeDef *htim)
{
  if (htim->Instance == TIM6)
  {
    HAL_IncTick();
  }
}

/**
  * @brief  This function is executed in case of error occurrence.
  * @retval None
  */
void Error_Handler(void)
{
  /* USER CODE BEGIN Error_Handler_Debug */
  /* User can add his own implementation to report the HAL error return state */
  __disable_irq();
  while (1)
  {
  }
  /* USER CODE END Error_Handler_Debug */
}
#ifdef USE_FULL_ASSERT
/**
  * @brief  Reports the name of the source file and the source line number
  *         where the assert_param error has occurred.
  * @param  file: pointer to the source file name
  * @param  line: assert_param error line source number
  * @retval None
  */
void assert_failed(uint8_t *file, uint32_t line)
{
  /* USER CODE BEGIN 6 */
  /* User can add his own implementation to report the file name and line number,
     ex: printf("Wrong parameters value: file %s on line %d\r\n", file, line) */
  /* USER CODE END 6 */
}
#endif /* USE_FULL_ASSERT */

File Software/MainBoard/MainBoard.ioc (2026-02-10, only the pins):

Mcu.UserName=STM32H723VGTx
PA0.Signal=ADC1_INP16
PA1.Signal=OCTOSPIM_P1_IO3
PA10.Signal=GPIO_Output
PA11.Signal=FDCAN1_RX
PA12.Signal=FDCAN1_TX
PA13(JTMS/SWDIO).Signal=DEBUG_JTMS-SWDIO
PA14(JTCK/SWCLK).Signal=DEBUG_JTCK-SWCLK
PA15(JTDI).Signal=GPIO_Input
PA2.Signal=OCTOSPIM_P1_IO0
PA3.Signal=USB_OTG_HS_ULPI_D0
PA4.Signal=PSSI_DE
PA5.Signal=USB_OTG_HS_ULPI_CK
PA6.Signal=PSSI_PDCK
PA7.Signal=OCTOSPIM_P1_IO2
PA8.Signal=USB_OTG_HS_SOF
PA9.Signal=SPI2_SCK
PB0.Signal=USB_OTG_HS_ULPI_D1
PB1.Signal=USB_OTG_HS_ULPI_D2
PB10.Signal=USB_OTG_HS_ULPI_D3
PB11.Signal=USB_OTG_HS_ULPI_D4
PB12.Signal=USB_OTG_HS_ULPI_D5
PB13.Signal=USB_OTG_HS_ULPI_D6
PB14.Signal=SPI2_MISO
PB15.Signal=SPI2_MOSI
PB2.Signal=OCTOSPIM_P1_CLK
PB3(JTDO/TRACESWO).Signal=SPI1_SCK
PB4(NJTRST).Signal=GPIO_Analog
PB5.Signal=USB_OTG_HS_ULPI_D7
PB6.Signal=GPIO_Analog
PB7.Signal=PSSI_RDY
PB8.Signal=PSSI_D6
PB9.Signal=PSSI_D7
PC0.Signal=USB_OTG_HS_ULPI_STP
PC1.Signal=ADCx_INP11
PC10.Signal=SPI3_SCK
PC11.Signal=PSSI_D4
PC12.Signal=SPI3_MOSI
PC13.Signal=GPIO_Input
PC14-OSC32_IN.Signal=GPIO_Input
PC15-OSC32_OUT.Signal=GPIO_Input
PC2_C.Signal=USB_OTG_HS_ULPI_DIR
PC3_C.Signal=USB_OTG_HS_ULPI_NXT
PC4.Signal=ADCx_INP4
PC5.Signal=ADCx_INP8
PC6.Signal=PSSI_D0
PC7.Signal=PSSI_D1
PC8.Signal=PSSI_D2
PC9.Signal=PSSI_D3
PD0.Signal=UART4_RX
PD1.Signal=UART4_TX
PD10.Signal=GPIO_Input
PD11.Signal=GPXTI11
PD12.Signal=OCTOSPIM_P1_IO1
PD13.Signal=GPXTI13
PD14.Signal=GPXTI14
PD15.Signal=GPXTI15
PD2.Signal=GPIO_Input
PD3.Signal=PSSI_D5
PD4.Signal=GPIO_Output
PD5.Signal=GPIO_Output
PD6.Signal=GPIO_Output
PD7.Signal=SPI1_MOSI
PD8.Signal=GPIO_Output
PD9.Signal=GPIO_Input
PE0.Signal=UART8_RX
PE1.Signal=UART8_TX
PE10.Signal=GPIO_Output
PE11.Signal=OCTOSPIM_P1_NCS
PE12.Signal=GPIO_Input
PE13.Signal=S_TIM1_CH3
PE14.Signal=GPIO_Output
PE15.Signal=GPIO_Output
PE2.Signal=GPIO_Input
PE3.Signal=GPIO_Output
PE4.Signal=GPIO_Output
PE5.Signal=S_TIM15_CH1
PE6.Signal=S_TIM15_CH2
PE7.Signal=GPIO_Output
PE8.Signal=GPIO_Output
PE9.Signal=GPIO_Output
PH0-OSC_IN.Signal=RCC_OSC_IN
PH1-OSC_OUT.Signal=RCC_OSC_OUT

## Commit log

2025-10-11 init commit
    [DebuggingBoard.kicad_pcb, DebuggingBoard.kicad_sch, LT8609SIV_PBF.step]
2025-10-13 added sim files and osc
    [ADS8866IDRCR.step, DebuggingBoard.kicad_sch, LT8609SIV_PBF.step]
2025-10-21 nearly final osc
    [DebuggingBoard.kicad_sch, PTPS7A9401DSCR.step]
2025-12-27 rack approach
    [DebuggingBoard.kicad_pcb, DebuggingBoard.kicad_sch]
2025-12-30 updated main:
    [DebuggingBoard.kicad_sch]
2026-01-03 VPSU and PMS complete
    [DebuggingBoard.kicad_sch, FuncGenBoard.kicad_pcb, FuncGenBoard.kicad_sch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]
2026-01-05 modified power flow
    [DebuggingBoard.kicad_pcb, DebuggingBoard.kicad_sch, PowerManagement.kicad_sch]
2026-01-05 update all files names
    [DebuggingBoard.kicad_pcb, DebuggingBoard.kicad_sch, FuncGenBoard.kicad_pcb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]
2026-01-06 VPSU schem complete
    [DebuggingBoard.kicad_sch, PowerManagement.kicad_sch, VPSUBoard.kicad_pcb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]
2026-01-07 usb hs config
    [DebuggingBoard.kicad_sch, VPSUBoard.kicad_pcb, VPSUBoard.kicad_sch]
2026-01-09 layout main
    [DebuggingBoard.kicad_pcb, DebuggingBoard.kicad_sch, PowerManagement.kicad_sch]
2026-01-13 new layout
    [DebuggingBoard.kicad_pcb, DebuggingBoard.kicad_sch, MultimeterBoard.kicad_sch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]
2026-01-13 updated connectors
    [DebuggingBoard.kicad_pcb, DebuggingBoard.kicad_sch]
2026-01-13 vpsu conn
    [DebuggingBoard.kicad_pcb, DebuggingBoard.kicad_sch]
2026-01-15 finished main
    [DebuggingBoard-B_Cu.gbr, DebuggingBoard-B_Mask.gbr, DebuggingBoard-B_Paste.gbr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]
2026-01-29 software unit testing
    [DebuggingBoard.kicad_pcb, PowerManagement.kicad_sch]
2026-02-04 LCD Test
    [DebuggingBoard.kicad_pcb]
2026-02-09 more usb debug
    [OscilloscopeBoard.kicad_sch]

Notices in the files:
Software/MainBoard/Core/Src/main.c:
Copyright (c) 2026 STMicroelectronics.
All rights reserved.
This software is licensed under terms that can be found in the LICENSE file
